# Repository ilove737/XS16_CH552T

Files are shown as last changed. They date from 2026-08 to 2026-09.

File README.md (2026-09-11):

# XS16_CH552T

## 介绍
基于CH552T微控制器实现的XS16键盘固件项目（16键，4×4 矩阵）。这是一个USB键盘/鼠标复合设备固件，使用CH552系列微控制器实现键盘和鼠标功能。

## 项目特点
- 支持USB键盘和鼠标功能（复合设备）
- 基于CH552T微控制器
- 支持键盘扫描矩阵（4行×4列，共16键）
- 包含定时器和GPIO控制功能
- 支持数据闪存存储

## 硬件平台
- 微控制器：CH552T
- 开发板：XS16

## 编译环境设置

### Linux编译环境
本项目已经配置为可以在Linux环境下使用SDCC编译器编译：

1. 安装SDCC编译器：
   ```bash
   make install-deps
   ```

2. 编译项目：
   ```bash
   make clean
   make all
   ```

3. 编译输出：
   - 生成的文件将存放在 `build/` 目录中
   - 链接中间产物：`build/XS16_CH552T.ihx`（SDCC 链接输出）
   - 最终固件：`build/XS16_CH552T.hex`（由 `.ihx` 经 `packihx` 转换，可烧录）

## 项目结构
- `src/main.c` - 主程序入口
- `src/CompositeKM.C/CompositeKM.H` - USB键盘鼠标复合设备实现
- `src/CH552.H` - SDCC兼容的CH552头文件
- `src/Debug.C/Debug.H` - 调试和延时函数
- `src/Timer.C/Timer.H` - 定时器功能
- `src/GPIO.C/GPIO.H` - GPIO控制功能
- `src/UART1.C/UART1.H` - UART1 串口功能
- `src/scanKey.c/scanKey.h` - 键盘扫描功能
- `src/DataFlash.C/DataFlash.H` - 数据闪存功能
- `src/FlashWrite.c/FlashWrite.h` - Flash 写入功能
- `src/keyMap.h` - 键位映射定义
- `Makefile` - Linux编译脚本

## 编译说明
- 使用SDCC (Small Device C Compiler) 进行编译
- 目标微控制器：CH552T
- 可用代码区：约 14KB（Makefile 中 `--code-size 0x3800`，CH552 的 16KB Flash 需给 Bootloader 留出空间）
- 已配置为支持USB设备模式

## 输出文件
- `XS16_CH552T.hex` - 可烧录的Intel HEX格式固件
- `XS16_CH552T.ihx` - Intel HEX格式中间文件
- 各种调试文件（.asm, .lst, .map等）在 build 目录中

## 烧录方式
生成的hex文件可以通过支持CH552的编程器进行烧录，例如：
- 使用本项目自带命令（需先安装 `wchisp`）：
  ```bash
  make flash          # 等价于 wchisp flash build/XS16_CH552T.hex
  ```
  其中 `wchisp` 可通过 `cargo install wchisp` 或各平台包管理器安装。
- ISP编程器
- 相关的CH55x专用烧录工具

## 注意事项
- 项目已适配SDCC编译器，不再依赖Keil C51
- 所有CH552特定寄存器定义已转换为SDCC兼容格式
- USB功能已适配CH552 USB控制器

## 配套工具

本项目除了固件，还提供了两个键位编辑器，用于图形化编辑固件的键位映射、场景配置，并通过 USB / WebHID 与设备通信。

### 桌面端编辑器（tools/app，Tauri v2）

基于 Tauri v2 的跨平台桌面应用（前端为无框架 Vanilla JS，后端为 Rust）。

- 提供图形化键位编辑、设备读写（HID 通信）。
- 场景名支持从当前打开的应用列表中选取（下拉选择框，窗口聚焦时自动刷新）。
- Linux 下连接键盘权限不足时，可自动安装 udev 规则（需输入管理员密码）。
- 支持「按激活应用自动切换场景」功能（见下节）。
- 构建方式：
  ```bash
  # Linux 下需先安装系统依赖
  sudo apt-get install -y libdbus-1-dev libudev-dev libgtk-3-dev \
    libwebkit2gtk-4.1-dev libjavascriptcoregtk-4.1-dev libsoup-3.0-dev

  cd tools/app && npm install   # 安装前端依赖
  npm run build                 # 打包前端到 dist/
  make -C tools/app app         # 构建发布包
  # 或 npm run tauri-dev 进行开发调试
  ```

### Web 端编辑器（tools/web，WebHID）

基于浏览器 WebHID 的纯前端编辑器，无需安装，适合快速修改键位。

- 受浏览器沙箱限制，无法读取前台窗口，因此**不支持**「自动匹配激活应用」功能。
- 启动方式：
  ```bash
  cd tools/web && python3 -m http.server 8000
  # 浏览器打开 http://localhost:8000 （WebHID 需 localhost 或 HTTPS）
  ```

## 自动匹配激活应用（场景自动切换）

编辑器在后台轮询当前前台（激活）窗口的应用名，与固件中配置的场景槽应用名匹配，命中即自动下发对应场景，未命中则切回主层（generic）。

- 实现位置：Rust 后端 `tools/app/src-tauri/src/lib.rs`
  （`active_app_impl` 取前台应用 + `match_app_to_scene` 匹配 + `poll_loop` 轮询下发）。
- **平台支持：**
  - ✅ **Linux**：通过 X11 协议（`x11rb` / `libxcb`）读取前台窗口，功能完整可用。
  - ⚠️ **macOS / Windows**：**暂不支持**。前台窗口探测依赖各平台原生窗口系统接口
    （macOS 的 `NSWorkspace`、Windows 的 `GetForegroundWindow` 等），
    当前版本仅在 Linux 上实现，路线图见下方 TODO。

## 待办 / 路线图

### 在 macOS / Windows 实现「自动匹配激活应用」功能（方案 A：原生 FFI）

> 目标：用 Rust 直接调用各平台原生窗口接口，替代当前仅 Linux 可用的 X11 实现，
> 使桌面端编辑器的「自动切换场景」功能在三个平台上都可用。

1. **[Cargo.toml]** 新增平台专属依赖：
   - macOS：`objc` / `cocoa`（调用 `NSWorkspace.frontmostApplication` 取 `bundleIdentifier` / `localizedName`）
   - Windows：`windows` 或 `winapi`（调用 `GetForegroundWindow` / `GetWindowThreadProcessId` / `QueryFullProcessImageName`）
2. **[lib.rs]** 把 `active_app_impl` 由「仅 Linux」改为三平台各自实现：
   - Linux：现有 X11 实现（保持不变）
   - macOS：Objective-C FFI 取前台应用标识
   - Windows：Win32 API 取前台窗口进程路径，解析出 exe 名
3. **[lib.rs]** `match_app_to_scene` / `send_scene_impl` / `poll_loop` 架构完全复用，
   仅「取前台应用名」一步做成平台可插拔（共用同一套匹配/下发逻辑）。
4. **[lib.rs]** 去掉 `active_app` / `get_poll_status` / `start_auto_poll` / `stop_auto_poll`
   中 `#[cfg(not(target_os = "linux"))]` 的 Err stub，改为各平台真实实现
   （或至少 macOS/Windows 各自实现，最后兜底返回 `Err`）。
5. **[CI]** 调整 `.github/workflows/build.yml`，确保 macOS / Windows target
   链接对应平台 SDK 成功（注意 Windows 的 MSVC vs gnu target 差异）。
6. **[前端 tools/app/src/app.js]** 把"自动匹配仅 Linux"的提示文案更新为按平台动态提示。

## 许可证
本项目固件基于 WCH（CH552）官方示例代码改编开发，遵循原示例代码所附许可；新增与修改部分目前**未声明明确许可证**，如需用于分发或二次开发请先联系作者确认。

> 说明：随 Tauri 依赖引入的第三方库（如 `tools/app/src-tauri/target/` 下）分别遵循其各自的许可证（如 Apache-2.0、MIT 等），与本仓库固件代码许可无关。

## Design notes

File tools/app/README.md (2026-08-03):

# XS16_CH552T 键位映射编辑器 — Tauri 桌面版

在 `tools/web/` 网页版基础上，改用 **Tauri v2** + **Rust hidapi** 实现的原生桌面工具。
无需浏览器，无需 WebHID，直接通过 HID Feature Report 读写键盘固件键位映射。

## 项目结构

```
app/
├── src/                          # 前端源码（Vanilla JS + esbuild 打包）
│   ├── index.html                # 主界面
│   ├── styles.css                # 样式
│   ├── app.js                    # 主逻辑
│   ├── ipc-hid.js                # HID IPC 桥接层（调用 Rust 后端）
│   ├── keymap.js                 # 键码表、解析逻辑（与 web 版共享）
│   └── capture.js                # 按键捕获（与 web 版共享）
├── dist/                         # 构建输出（esbuild 打包产物）
├── src-tauri/                    # Rust 后端
│   ├── src/lib.rs                # 5 个 IPC 命令
│   ├── src/main.rs               # 入口
│   ├── Cargo.toml                # 依赖：tauri 2 + hidapi 2
│   ├── tauri.conf.json           # 窗口配置
│   └── capabilities/default.json # 权限
├── package.json
└── README.md
```

## 前置依赖

| 工具 | 版本要求 | 备注 |
|---|---|---|
| Rust | ≥ 1.70 | `rustc --version` |
| Node.js | ≥ 18 | `node --version` |
| npm | 随 Node.js | `npm --version` |

### Linux 系统库

```bash
sudo apt-get install -y libwebkit2gtk-4.1-dev libsoup-3.0-dev
```

若之前装过旧版 `libwebkit2gtk-4.0-dev`，Tauri v2 需要 4.1 版本。

## 构建 & 运行

```bash
cd tools/app

# 安装前端依赖
npm install

# 开发模式运行
npm run tauri-dev

# 或分步执行：
# npm run build          # 构建前端 bundle
# cargo tauri dev         # 启动开发模式

# 生产打包
cargo tauri build        # 输出到 src-tauri/target/release/bundle/
```

## 跨平台

| 平台 | HID 后端 | 注意事项 |
|---|---|---|
| Linux | hidapi → hidraw | 需要 udev 规则，见下方 |
| macOS | hidapi → IOHIDManager | 无需额外驱动 |
| Windows | hidapi → 原生 HID | 无需 libusb |

### Linux udev 规则

读写键盘键位映射需要访问 `/dev/hidraw*` 设备节点：

```bash
echo 'SUBSYSTEM=="hidraw", ATTRS{idVendor}=="4c58", ATTRS{idProduct}=="5310", MODE="0666"' \
  | sudo tee /etc/udev/rules.d/99-xs16-keyboard.rules
sudo udevadm control --reload-rules
sudo udevadm trigger
```

## 常见问题

### 窗口白屏，日志中出现 KMS/DRM 权限错误

```
KMS: DRM_IOCTL_MODE_CREATE_DUMB failed: 权限不够
Failed to create GBM buffer of size 1100x760: 权限不够
```

**原因**：当前用户不在 `render` 组，无法访问 GPU 渲染节点。

**临时绕过**：
```bash
WEBKIT_DISABLE_COMPOSITING_MODE=1 cargo tauri dev
```

**永久解决**：
```bash
sudo usermod -a -G render $USER
```
然后注销重新登录，或重启。

### 窗口白屏，日志中出现 GLib-GObject-CRITICAL

```
GLib-GObject-CRITICAL: g_value_set_boxed: assertion 'G_VALUE_HOLDS_BOXED (value)' failed
```

通常是 GPU 渲染失败的级联错误。先解决上面的 GPU 权限问题。

### 编译时找不到 hidapi

```bash
# Linux
sudo apt-get install -y libhidapi-dev

# macOS
brew install hidapi

# Windows（MSYS2）
pacman -S mingw-w64-x86_64-hidapi
```

Rust 的 hidapi crate 会自动链接系统库，缺少时会编译失败。

## 技术栈

| 层 | 技术 |
|---|---|
| 窗口/打包 | Tauri v2 |
| 前端 | HTML + CSS + Vanilla JS（esbuild 打包） |
| HID 通信 | Rust hidapi 2.x |
| IPC 桥接 | `@tauri-apps/api` invoke |

### Rust 后端 IPC 命令

| 命令 | 参数 | 说明 |
|---|---|---|
| `list_devices` | 无 | 枚举 VID=0x4C58, PID=0x5310 的设备 |
| `open_device` | path | 按路径打开设备 |
| `close_device` | path | 关闭设备 |
| `read_keymap` | path | 读取 64 字节键位映射 |
| `write_keymap` | path, data | 写入 64 字节键位映射 |

## 与 web 版的区别

| 对比项 | web 版 (NW.js) | Tauri 版 |
|---|---|---|
| 运行时 | ~150MB (NW.js) | ~5MB (Tauri) |
| HID 方式 | 浏览器 WebHID | Rust hidapi |
| 前端代码 | 全部 | 复用 keymap.js / capture.js |
| 设备枚举 | 系统弹窗授权 | 直接调用 hidapi |
| 跨平台 | 三平台 | 三平台 |

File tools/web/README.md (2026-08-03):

# XS16_CH552T 键位映射编辑器 (WebHID)

基于 WebHID 的 XS16 键盘键位配置工具，无需安装驱动或后端服务。

## 使用方式

### 本地使用（推荐）

```bash
./serve-app.sh
```

自动启动 HTTP 服务并用 Chrome 应用模式打开编辑器。

### 远程使用（HTTPS 必需）

Chrome 的 WebHID API 需要安全上下文（HTTPS 或 localhost）。远程访问时需配置 HTTPS：

```bash
# 1. 安装 mkcert
sudo apt install libnss3-tools
wget https://github.com/FiloSottile/mkcert/releases/latest/download/mkcert-v1.4.4-linux-amd64
chmod +x mkcert-v1.4.4-linux-amd64
sudo mv mkcert-v1.4.4-linux-amd64 /usr/local/bin/mkcert
mkcert -install

# 2. 为域名生成证书
mkcert 你的域名

# 3. 启动 HTTPS 服务
./serve-app.sh --https 你的域名
```

浏览器访问 `https://你的域名:8000`。

### 手动启动

```bash
# HTTP（仅 localhost 可用）
python3 -m http.server 8000

# HTTPS（远程可用）
python3 -c "
import http.server, ssl
ctx = ssl.SSLContext(ssl.PROTOCOL_TLS_SERVER)
ctx.load_cert_chain(certfile='域名.pem', keyfile='域名-key.pem')
httpd = http.server.HTTPServer(('0.0.0.0', 8000), http.server.SimpleHTTPRequestHandler)
httpd.socket = ctx.wrap_socket(httpd.socket, server_side=True)
httpd.serve_forever()
"
```

## 功能说明

- **16 键网格**：主编辑区，显示当前层的键位映射
- **104 键盘图**：编辑弹窗中的可视化按键选择器，支持点击选择键位
- **按键捕获**：编辑弹窗中自动捕获物理键盘按键，联动 104 键盘图高亮
- **组合键支持**：修饰键（Ctrl/Shift/Alt/Win）点击切换复选框，支持组合键选择
- **鼠标动作**：Fn0 层支持鼠标动作（左键/右键/移动/滚轮）
- **导入导出**：支持 `.txt`（可读格式）和 `.bin`（原始二进制）格式

## 文件结构

```
tools/web/
├── index.html       # 主页面
├── app.js           # 主逻辑（UI 控制、网格渲染、编辑弹窗、设备通信）
├── keymap.js        # 键码表、修饰符、布局数据、解析/格式化
├── hid.js           # WebHID 通信层
├── capture.js       # 键盘按键捕获
├── styles.css       # 样式
├── serve-app.sh     # 一键启动脚本（支持 HTTP/HTTPS）
├── manifest.json    # PWA 清单
├── icon.svg         # 应用图标
└── README.md        # 本文件
```

## 浏览器兼容性

需要 Chrome 89+ 或 Edge 89+，支持 WebHID API。

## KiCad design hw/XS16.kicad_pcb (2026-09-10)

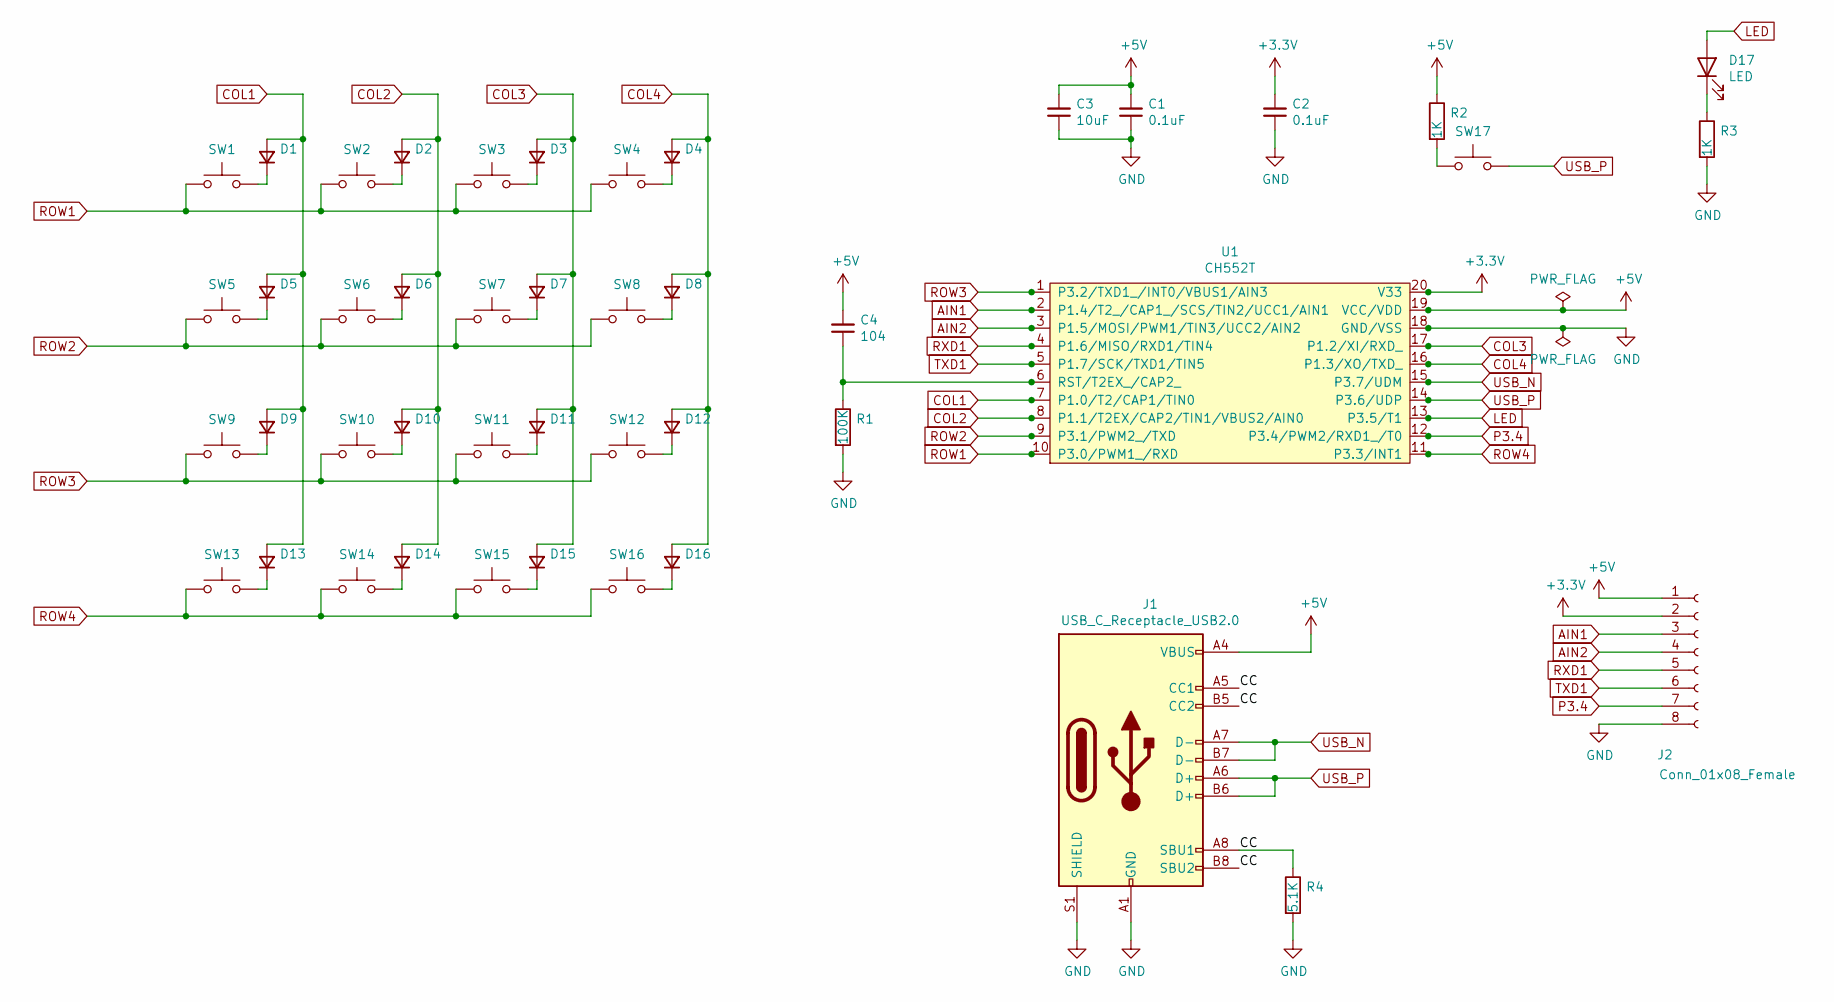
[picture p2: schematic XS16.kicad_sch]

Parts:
C1, C2: 0.1uF; C_0603_1608Metric
C3: 10uF; C_0603_1608Metric
C4: 104; C_0603_1608Metric
D1, D2, D3, D4, D5, D6, D7, D8, D9, D10, D11, D12, D13, D14, D15, D16: 1N4148; D_SOD-323
D17: LED; LED_0603_1608Metric
J1: USB_C_Receptacle_USB2.0; USB_C_Receptacle_Palconn_UTC16-G
J2: Conn_01x08_Female; PinHeader_1x08_P2.54mm_Vertical
R1: 100K; R_0603_1608Metric
R2, R3: 1K; R_0603_1608Metric
R4: 5.1K; R_0603_1608Metric
SW1, SW2, SW3, SW4, SW5, SW6, SW7, SW8, SW9, SW10, SW11, SW12, SW13, SW14, SW15, SW16: SW_Push; SW_Cherry_MX1A_1.00u_PCB_lxs
SW17: SW_Push; SW_Push_1P1T_NO_CK_KMR2
U1: CH552T; TSSOP-20_4.4x6.5mm_P0.65mm

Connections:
+3V3: C2.2, J2.2, U1.20 (V33)
+5V: C1.2, C3.2, C4.2, J1.A4 (VBUS), J1.A9 (VBUS), J1.B4 (VBUS), J1.B9 (VBUS), J2.1, R2.1, U1.19 (VCC/VDD)
/CC: J1.A5 (CC1), J1.A8 (SBU1), J1.B5 (CC2), J1.B8 (SBU2), R4.1
AIN1: J2.3, U1.2 (P1.4/T2_/CAP1_/SCS/TIN2/UCC1/AIN1)
AIN2: J2.4, U1.3 (P1.5/MOSI/PWM1/TIN3/UCC2/AIN2)
COL1: D1.2 (A), D5.2 (A), D9.2 (A), D13.2 (A), U1.7 (P1.0/T2/CAP1/TIN0)
COL2: D2.2 (A), D6.2 (A), D10.2 (A), D14.2 (A), U1.8 (P1.1/T2EX/CAP2/TIN1/VBUS2/AIN0)
COL3: D3.2 (A), D7.2 (A), D11.2 (A), D15.2 (A), U1.17 (P1.2/XI/RXD_)
COL4: D4.2 (A), D8.2 (A), D12.2 (A), D16.2 (A), U1.16 (P1.3/XO/TXD_)
GND: C1.1, C2.1, C3.1, J1.A1 (GND), J1.A12 (GND), J1.B1 (GND), J1.B12 (GND), J1.S1 (SHIELD), J1.SH, J2.8, R1.2, R3.2, R4.2, U1.18 (GND/VSS)
LED: D17.2 (A), U1.13 (P3.5/T1)
unnamed: C4.1, R1.1, U1.6 (RST/T2EX_/CAP2_)
unnamed: D1.1 (K), SW1.2
unnamed: D2.1 (K), SW2.2
unnamed: D3.1 (K), SW3.2
unnamed: D4.1 (K), SW4.2
unnamed: D5.1 (K), SW5.2
unnamed: D6.1 (K), SW6.2
unnamed: D7.1 (K), SW7.2
unnamed: D8.1 (K), SW8.2
unnamed: D9.1 (K), SW9.2
unnamed: D10.1 (K), SW10.2
unnamed: D11.1 (K), SW11.2
unnamed: D12.1 (K), SW12.2
unnamed: D13.1 (K), SW13.2
unnamed: D14.1 (K), SW14.2
unnamed: D15.1 (K), SW15.2
unnamed: D16.1 (K), SW16.2
unnamed: D17.1 (K), R3.1
unnamed: R2.2, SW17.1
P3.4: J2.7, U1.12 (P3.4/PWM2/RXD1_/T0)
ROW1: SW1.1, SW2.1, SW3.1, SW4.1, U1.10 (P3.0/PWM1_/RXD)
ROW2: SW5.1, SW6.1, SW7.1, SW8.1, U1.9 (P3.1/PWM2_/TXD)
ROW3: SW9.1, SW10.1, SW11.1, SW12.1, U1.1 (P3.2/TXD1_/INT0/VBUS1/AIN3)
ROW4: SW13.1, SW14.1, SW15.1, SW16.1, U1.11 (P3.3/INT1)
RXD1: J2.5, U1.4 (P1.6/MISO/RXD1/TIN4)
TXD1: J2.6, U1.5 (P1.7/SCK/TXD1/TIN5)
USB_N: J1.A7 (D-), J1.B7 (D-), U1.15 (P3.7/UDM)
USB_P: J1.A6 (D+), J1.B6 (D+), SW17.2, U1.14 (P3.6/UDP)

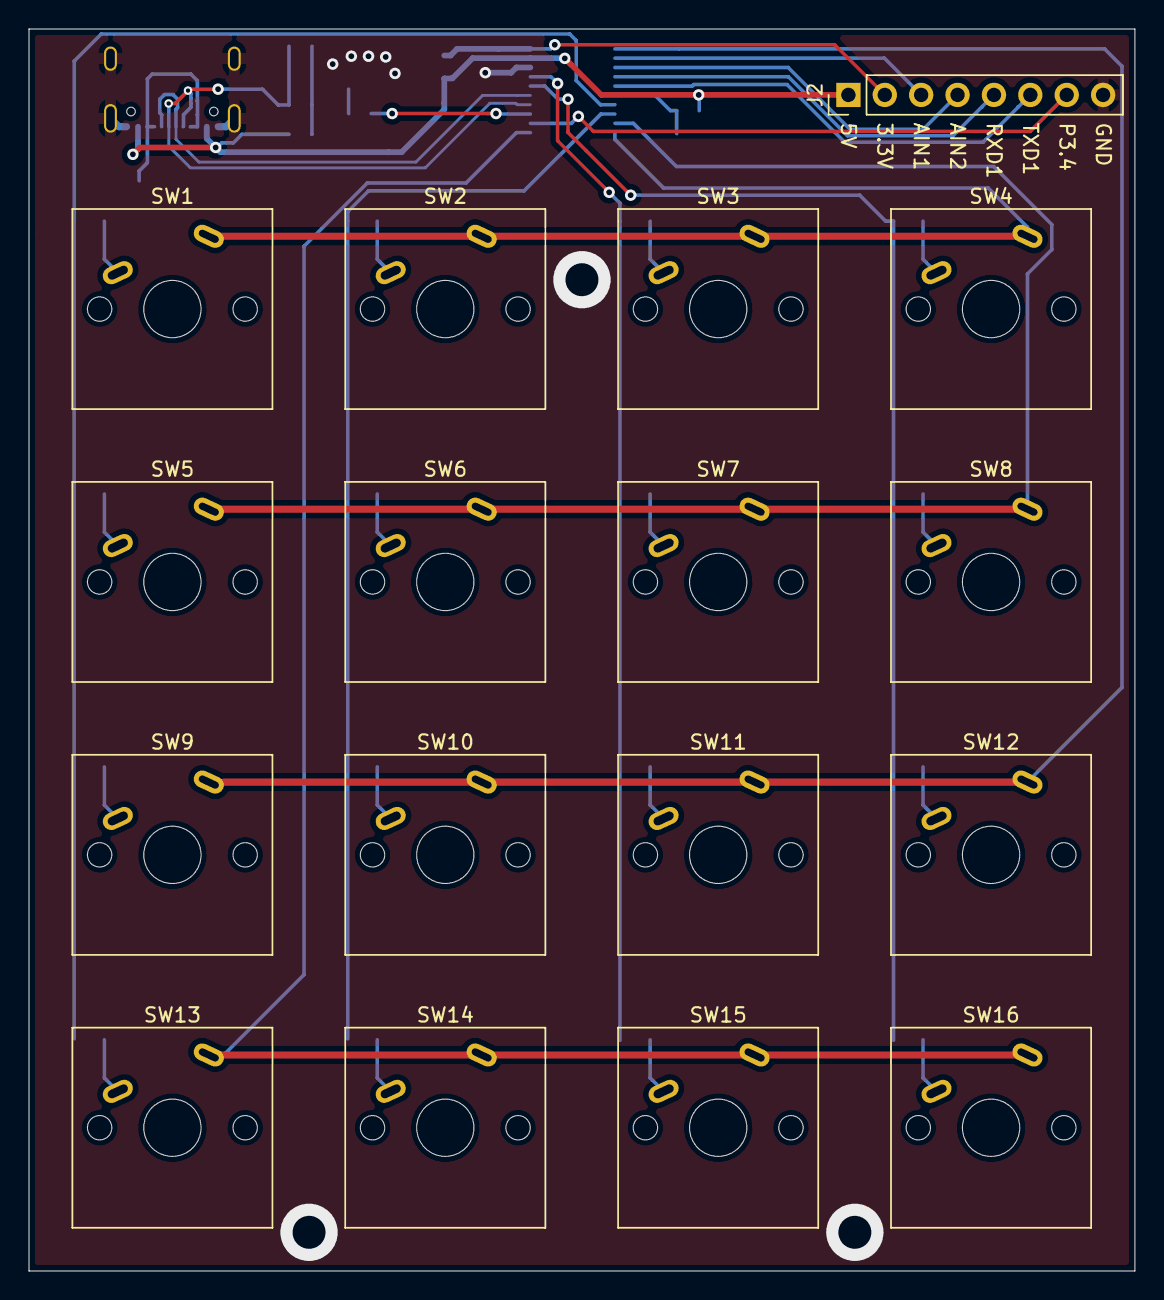
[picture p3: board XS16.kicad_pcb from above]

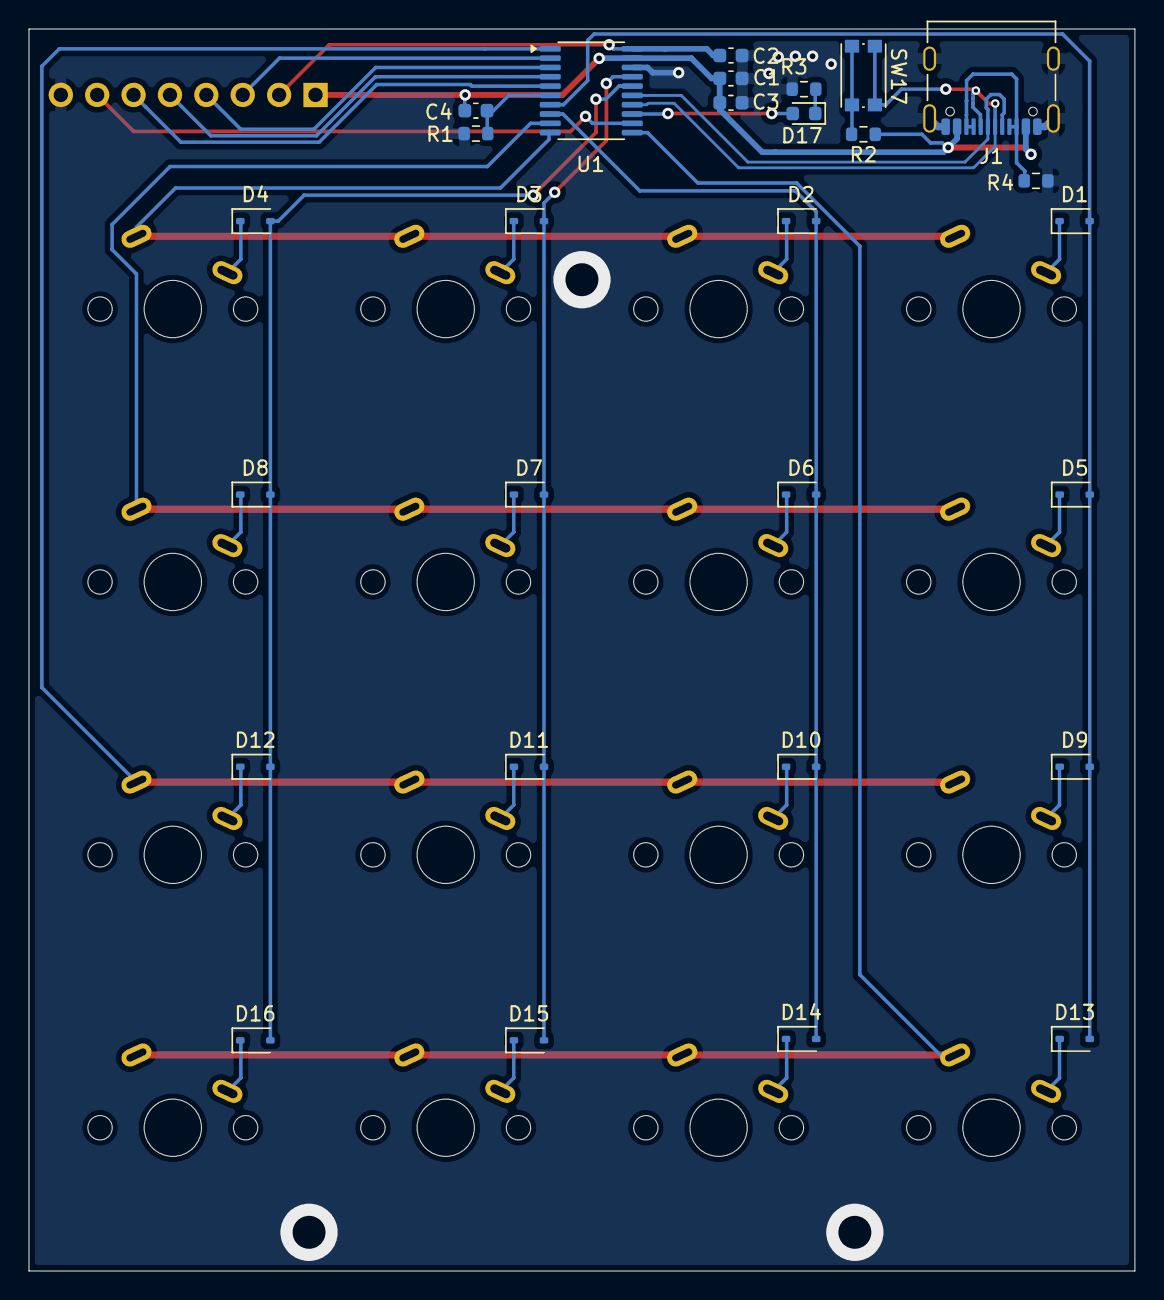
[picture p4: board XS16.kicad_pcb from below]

Board: 2 copper layers, 77.2 x 86.7 mm, 45 parts (28 on the bottom side), 39 nets.

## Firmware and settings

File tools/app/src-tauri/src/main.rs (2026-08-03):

// Prevents additional console window on Windows in release
#![cfg_attr(not(debug_assertions), windows_subsystem = "windows")]

fn main() {
    // Linux 下强制 CPU 渲染 WebView。NVIDIA 专有驱动即使 /dev/dri/renderD128
    // 可 open，实际 GBM 操作仍可能因权限不足失败导致白屏。此工具无需 GPU 加速。
    #[cfg(target_os = "linux")]
    std::env::set_var("WEBKIT_DISABLE_COMPOSITING_MODE", "1");

    xs16_keymap_tauri::run();
}

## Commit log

2026-08-03 XS16 CH552T：16键（4x4）deepin 快捷键键盘
    - 固件：CH552 复合 HID（键盘+鼠标），4x4 布局
    - 主层：deepin 系统快捷键（Ctrl+Alt+T、Super+E 等）
    - Fn 层：鼠标/方向控制
    - 设备 ID 改为 4C58:5310
    - Tauri 桌面应用（tools/app）+ Web 工具（tools/web）
    - 新增 Makefile 用于构建/运行
2026-08-04 firmware: 键位映射重构为6场景槽，场景下行走EP0 SET_REPORT，Flash读写扩展至480字节
    - keyMap.h: 键位映射改为 sceneMapTable[6][80]，每槽=16应用名+32主层+32Fn层，
    新增 SCENE_MAX/MAP_MAIN_OFF/MAP_FN_OFF/SCENE_CMD_MAGIC 等宏
    - CompositeKM: 新增厂商 Output 报告(Report ID=2, magic 0x5C)经 EP0 SET_REPORT 接收场景命令，
    更新 currentScene；CfgDesc 改为3接口77字节，IF2 无中断端点；
    键位缓冲统一为 KeymapBuf[481]，GET_REPORT 读481字节、SET_REPORT 收满写 Flash
    - scanKey: makeHIDFrames 依据 currentScene 从 sceneMapTable[currentScene] 选择主/Fn层键位
    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
2026-08-04 app: 新增X11前台应用检测与场景自动下发，前端支持6场景槽编辑
    - lib.rs: 纯Rust实现X11前台窗口检测(_NET_ACTIVE_WINDOW+WM_NAME+_NET_WM_PID)，
    poll_loop 线程自动匹配场景并经 send_scene(Report ID=2) 下发，last_scene 去重；
    write_keymap 改用 GetReport 读481字节；常量对齐固件场景槽
    - keymap.js/app.js/ipc-hid.js: 支持6场景槽键位编辑(getKeyAt/setKeyAt)、场景展示，
    切换逻辑移至后端
    - Makefile: app/dev 目标由 tauri build/dev 改为 cargo build/dev，移除 sysctl 目标
2026-08-04 refactor(app): 用激活场景绿色原点高亮替代当前应用栏
    - 移除工具栏"刷新当前应用"按钮与 activeAppInfo 文本栏
    - 新增 activeScene 状态，轮询 get_poll_status 仅高亮外部激活场景（绿色原点）
    - highlightScene 区分选中态(active)与激活高亮态(active-poll)
    - 配套新增 .scene-item.active-poll 样式
2026-08-04 前端: 移除 sidebar 设备树, editor 同时并排绘制主层/Fn 层
    - 删除左侧 sidebar 设备/层树形结构及连接/刷新按钮, 当前仅支持单台 XS16
    - editor 改为主层与 Fn 层左右并排双网格, 点击任一键编辑对应层键位
    - selectDevice 不再带 layer 参数, 层概念改为 openEdit/onOk 局部传参
    - 启动自动枚举并选中第一台设备 (autoConnect)
    - 窗口宽度 1100 -> 960 适配无 sidebar 布局
2026-08-04 fix: 将 IF2 接口 class 改为 0xFF 避免内核 usbhid 绑定报找不到中断端点警告
2026-08-04 fix: list_devices 只取第一个 HID 接口，避免单台设备被识别成多个
2026-08-04 feat: 新增 Deepin 终端快捷键页面并接入编辑弹窗
    - keymap.js: 新增 DEEPIN_TERMINAL_SHORTCUTS（终端/标签页/工作区/其他分类）
    - app.js: buildDeepinList 支持数据源切换，新增系统/终端子标签
    - index.html: deepin fieldset 内加入系统快捷键/终端快捷键子标签
    - styles.css: 新增 deepin 子标签样式
2026-08-04 feat: 添加关闭窗口最小化到系统托盘功能
    - 启用 tauri tray-icon/image-png 特性，主窗口显式 label=main
    - setup_tray 创建托盘图标与右键菜单(显示窗口/退出)，左键点击恢复窗口
    - on_window_event 拦截 CloseRequested 改为隐藏到托盘而非退出
    - 退出时(RunEvent::ExitRequested)停止自动轮询线程
    - 前端首次关闭窗口给出托盘提示(localStorage 去重)
2026-08-06 fix: 修复 Deepin/DDE 任务栏图标不显示并 redesign 为 4x4 键帽图标
    - lib.rs: 新增 set_x11_window_icon，在 X11 下直接写 _NET_WM_ICON
    (Tauri v2 set_icon 未写入该属性，导致 DDE 任务栏显示默认图标)
    - Cargo.toml: 新增 raw-window-handle 依赖
    - icons: 重新设计为 4x4 键盘按键布局 512/1024 及多尺寸 PNG + ICO
    - icons/gen_icon.py: 添加图标生成脚本，支持参数化键帽尺寸与间距
2026-08-06 fix: 锁屏后 no active window 刷屏问题（语义降级为空应用）
2026-08-06 fix: 修复 stop_poll_on_exit 借用生命周期编译错误
2026-08-06 feat: 系统全局热键用 deepin 蓝标识（不跟随场景色）
    - app.js: 新增 SYSKEY_COLOR 常量，keyDisplay 增加 matchedSource 参数，
    renderOne 改为两段式匹配（先场景专属表，未命中兜底 system 表）
    - 修复 classList.add 传入含空格类名字符串导致 InvalidCharacterError、
    后续按钮不渲染的 bug（改为 split(' ') 展开）
    - styles.css: 新增 .key-btn.key-sys 规则，系统热键用 deepin 蓝外框/顶面
    - 同步更新 src/keyMap.h、keymap.js
2026-08-06 fix(app): 编辑弹窗点击按键时按当前场景自动索引 Deepin 系统/终端快捷键
2026-08-06 feat: 更新默认键位映射并补充 Fn 层
2026-08-06 feat: 场景2 默认键位改为 VS Code 快捷键布局
    - 固件槽2（应用名 code）主层改为 VS Code 编辑快捷键，Fn 层为调试/重构/查找
    - 桌面端默认键位（makeDefaultKeymap）与固件保持一致
    - 编辑弹窗新增 VSCODE_SHORTCUTS 快速选择表及 VS Code 标签
    - code 场景网格按键显示快捷键中文名
2026-08-06 feat: 槽3 默认键位改为 deepin 文件管理器快捷键布局
    - 固件槽3（应用名 file-manager）主层/Fn 层按 DEEPIN_FILEMANAGER_SHORTCUTS 配置
    - 编辑弹窗新增文件管理器快捷键标签（位于 VS Code 之前）
    - 场景来源识别改为容错匹配，兼容 dde-file-manage/dde-file-manager/file-manager 命名
    - 文件管理器场景网格按键显示中文名
    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
2026-08-07 fix(front-end): 修正 104 键布局图小键盘键码错位（1/2/3 与 7/8/9 对调）
2026-08-07 fix(app): 替换废弃的 raw_window_handle API 为 HasWindowHandle
    raw-window-handle 0.6 中 HasRawWindowHandle 与 raw_window_handle() 已废弃，
    改用 HasWindowHandle / window_handle() / as_ref() 匹配 RawWindowHandle 枚举。
2026-08-07 feat(app): 添加日志框显示激活应用与导出路径，场景号呼吸光晕
    - 在键盘网格下方新增日志框，实时显示前台应用变化与场景切换
    - 导出文件改用 Tauri 保存对话框，日志框显示完整保存路径
    - 外部激活场景指示从绿点改为场景号绿色呼吸光晕动画
    - 移除场景项中无意义的「主层 / Fn 层」静态文本
2026-08-07 fix(app): 用 linux 条件编译包裹 raw_window_handle 导入以兼容 mac/win
2026-08-07 fix(app): 将 x11rb 依赖限定为 Linux，修复 Windows/macOS 链接 libxcb 失败
2026-08-11 fix(app): 修复 macOS/Windows 因 -D warnings 导致的编译错误
2026-08-11 docs: 补充配套工具介绍并说明自动匹配激活应用功能（macOS/Windows 暂不支持）
2026-08-18 docs: 修正 README 与实际结构/命令不符之处
2026-09-10 feat(hw): 添加 XS16 键盘 PCB 硬件设计文件
    包含 KiCad 工程（原理图、PCB、符号与封装库）以及 Gerber 生产文件。
    [XS16-B_Adhesive.gbr, XS16-B_Cu.gbr, XS16-B_Mask.gbr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]
2026-09-11 feat: 场景名下拉选择窗口应用 + 自动安装udev规则
    - 后端新增 list_windows 命令，通过 X11 _NET_CLIENT_LIST 获取所有打开的窗口列表
    - 后端新增 install_udev_rule 命令，通过 pkexec 自动安装 udev 规则解决权限问题
    - 后端提取 read_window_info 辅助函数，复用窗口信息读取逻辑
    - 前端场景名从输入框改为下拉选择框，显示当前打开的应用列表（按 app_name 去重）
    - 下拉框支持自定义输入，窗口聚焦时自动刷新应用列表
    - autoConnect 检测权限错误时弹窗提示安装 udev 规则
2026-09-11 docs: 更新 README 补充场景名下拉选择和 udev 自动安装说明
